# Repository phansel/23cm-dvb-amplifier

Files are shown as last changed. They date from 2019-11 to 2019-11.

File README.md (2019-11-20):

# 23cm DVB amplifier

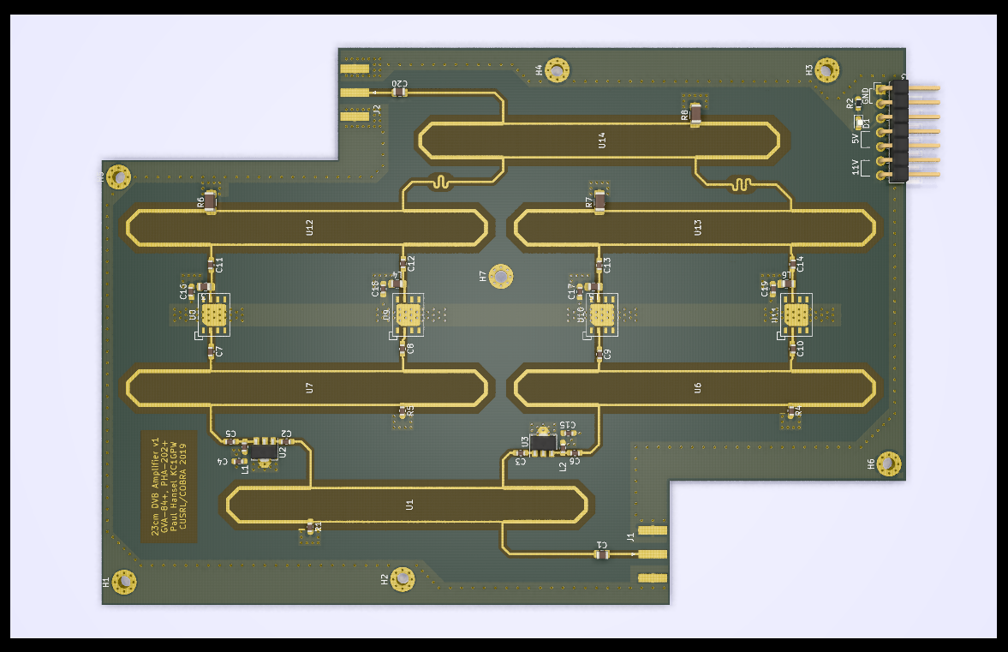
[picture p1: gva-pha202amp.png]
23cm DVB amplifier Amplifier image


This amplifier was designed in early 2019 for use as a telemetry/DVB radio for the University of Colorado COBRA/SRL rocket avionics project.

- ~ 4 watts (36 dBm) power output
- ~ 45 dB gain
- 1249 MHz center frequency

Note: editing this project requires at least KiCAD 5.99.

Copyright Paul Hansel (KC1GPW), 2019

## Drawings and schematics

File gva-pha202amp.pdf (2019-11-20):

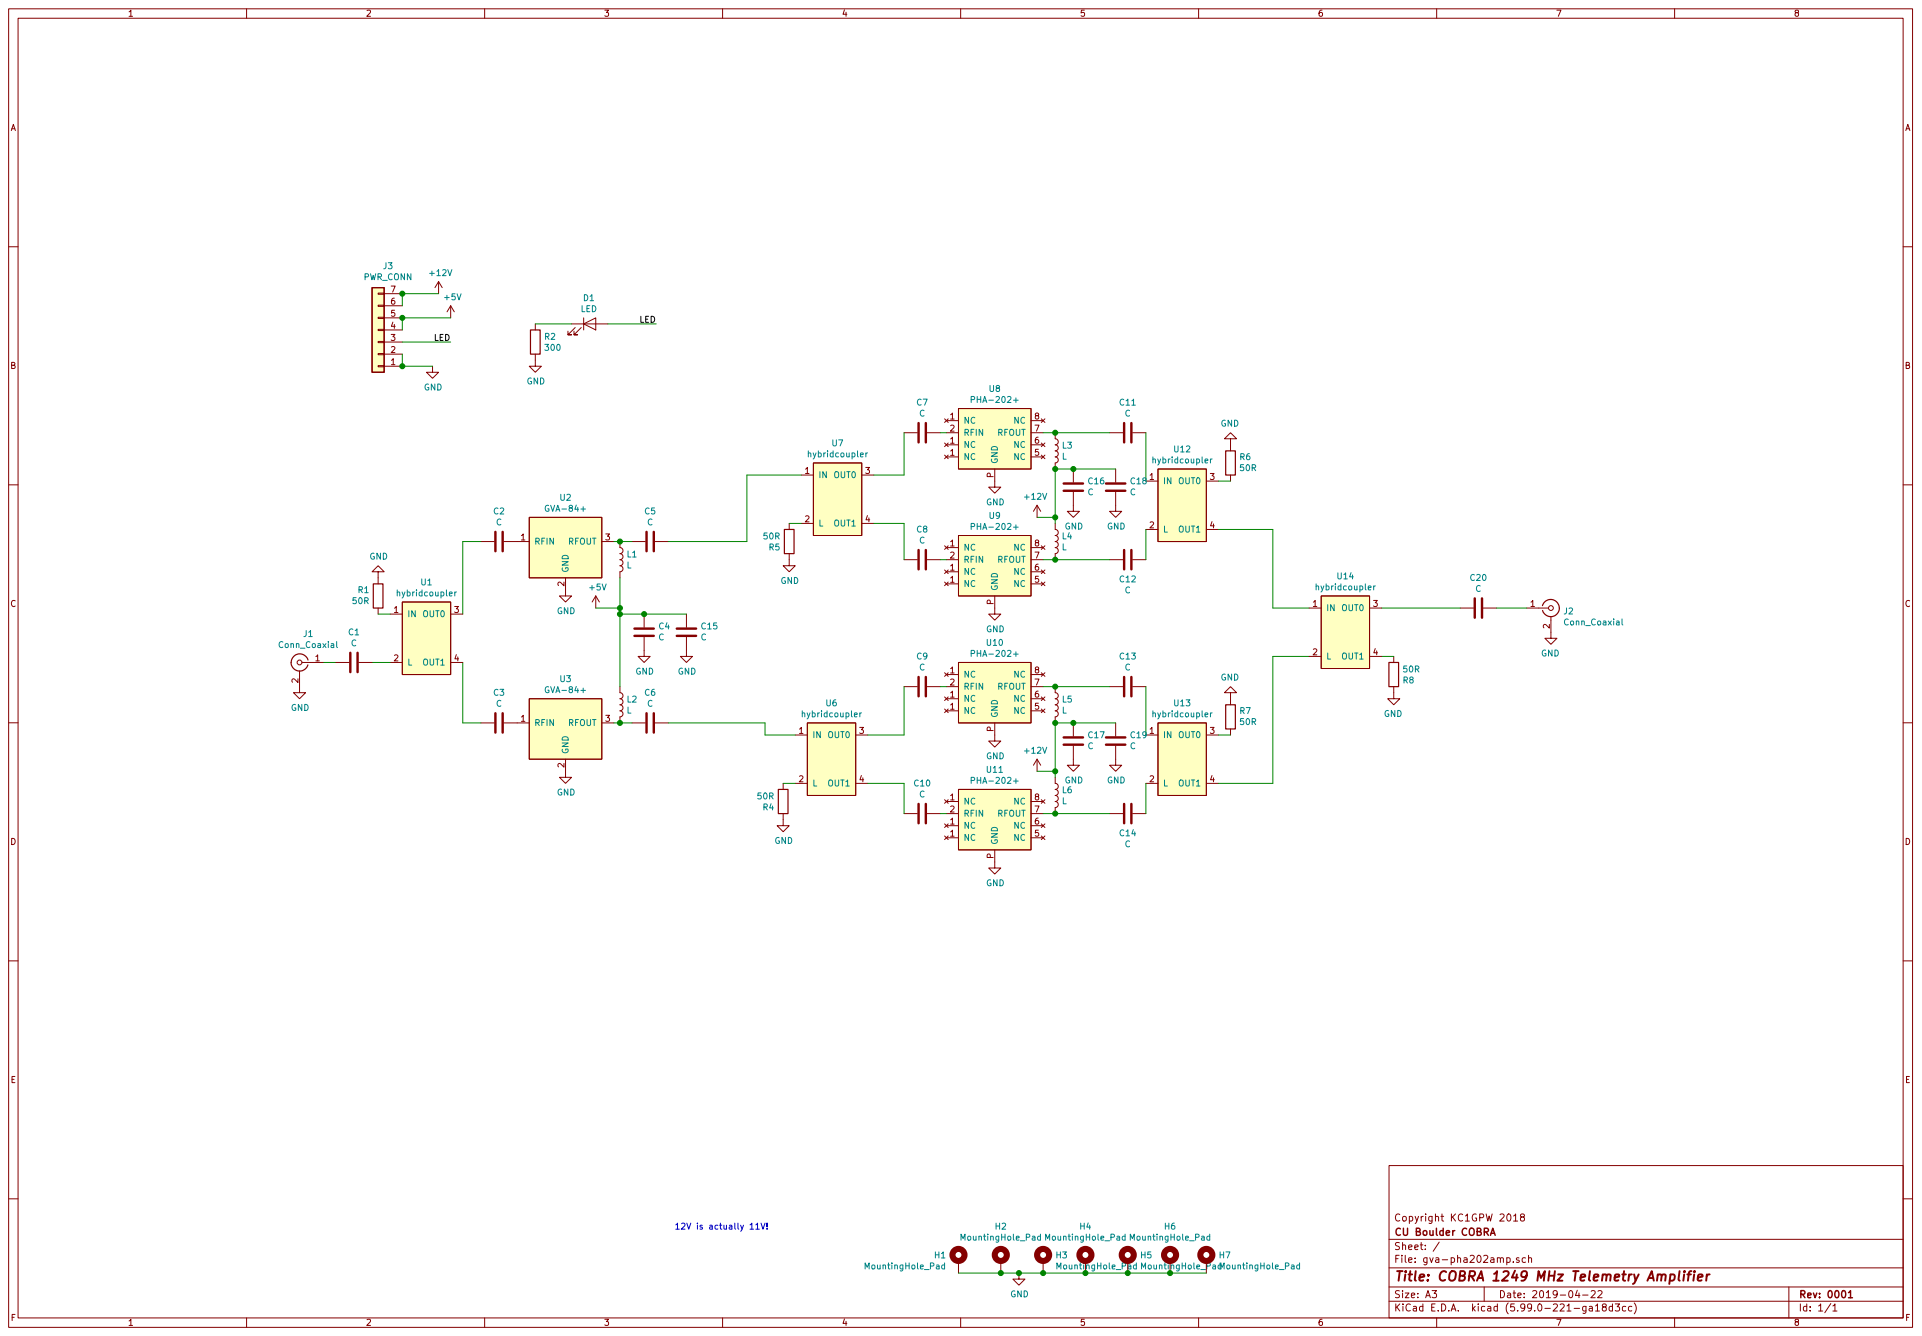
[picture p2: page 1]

P U8 PHA-202+ NC 1 NC 1 NC 1 RFIN 2 NC 5 NC 6 RFOUT 7 NC 8 GND

2 RFOUT 3 U3 GVA-84+ NC 1 NC 1 NC 1 RFIN 2 NC 5 NC 6 RFOUT 7 NC 8 GND

2 RFOUT 3 U2 GVA-84+ RFIN 1 GND

P U11 PHA-202+ GND GND GND GND

P U9 PHA-202+ NC 1 NC 1 NC 1 RFIN 2 NC 5 NC 6 RFOUT 7 NC 8 GND

P U10 PHA-202+ NC 1 NC 1 NC 1 RFIN 2 NC 5 NC 6 RFOUT 7 NC 8 GND

Copyright KC1GPW 2018
File: gva-pha202amp.sch Sheet: / CU Boulder COBRA

Id: 1/1 Title: COBRA 1249 MHz Telemetry Amplifier

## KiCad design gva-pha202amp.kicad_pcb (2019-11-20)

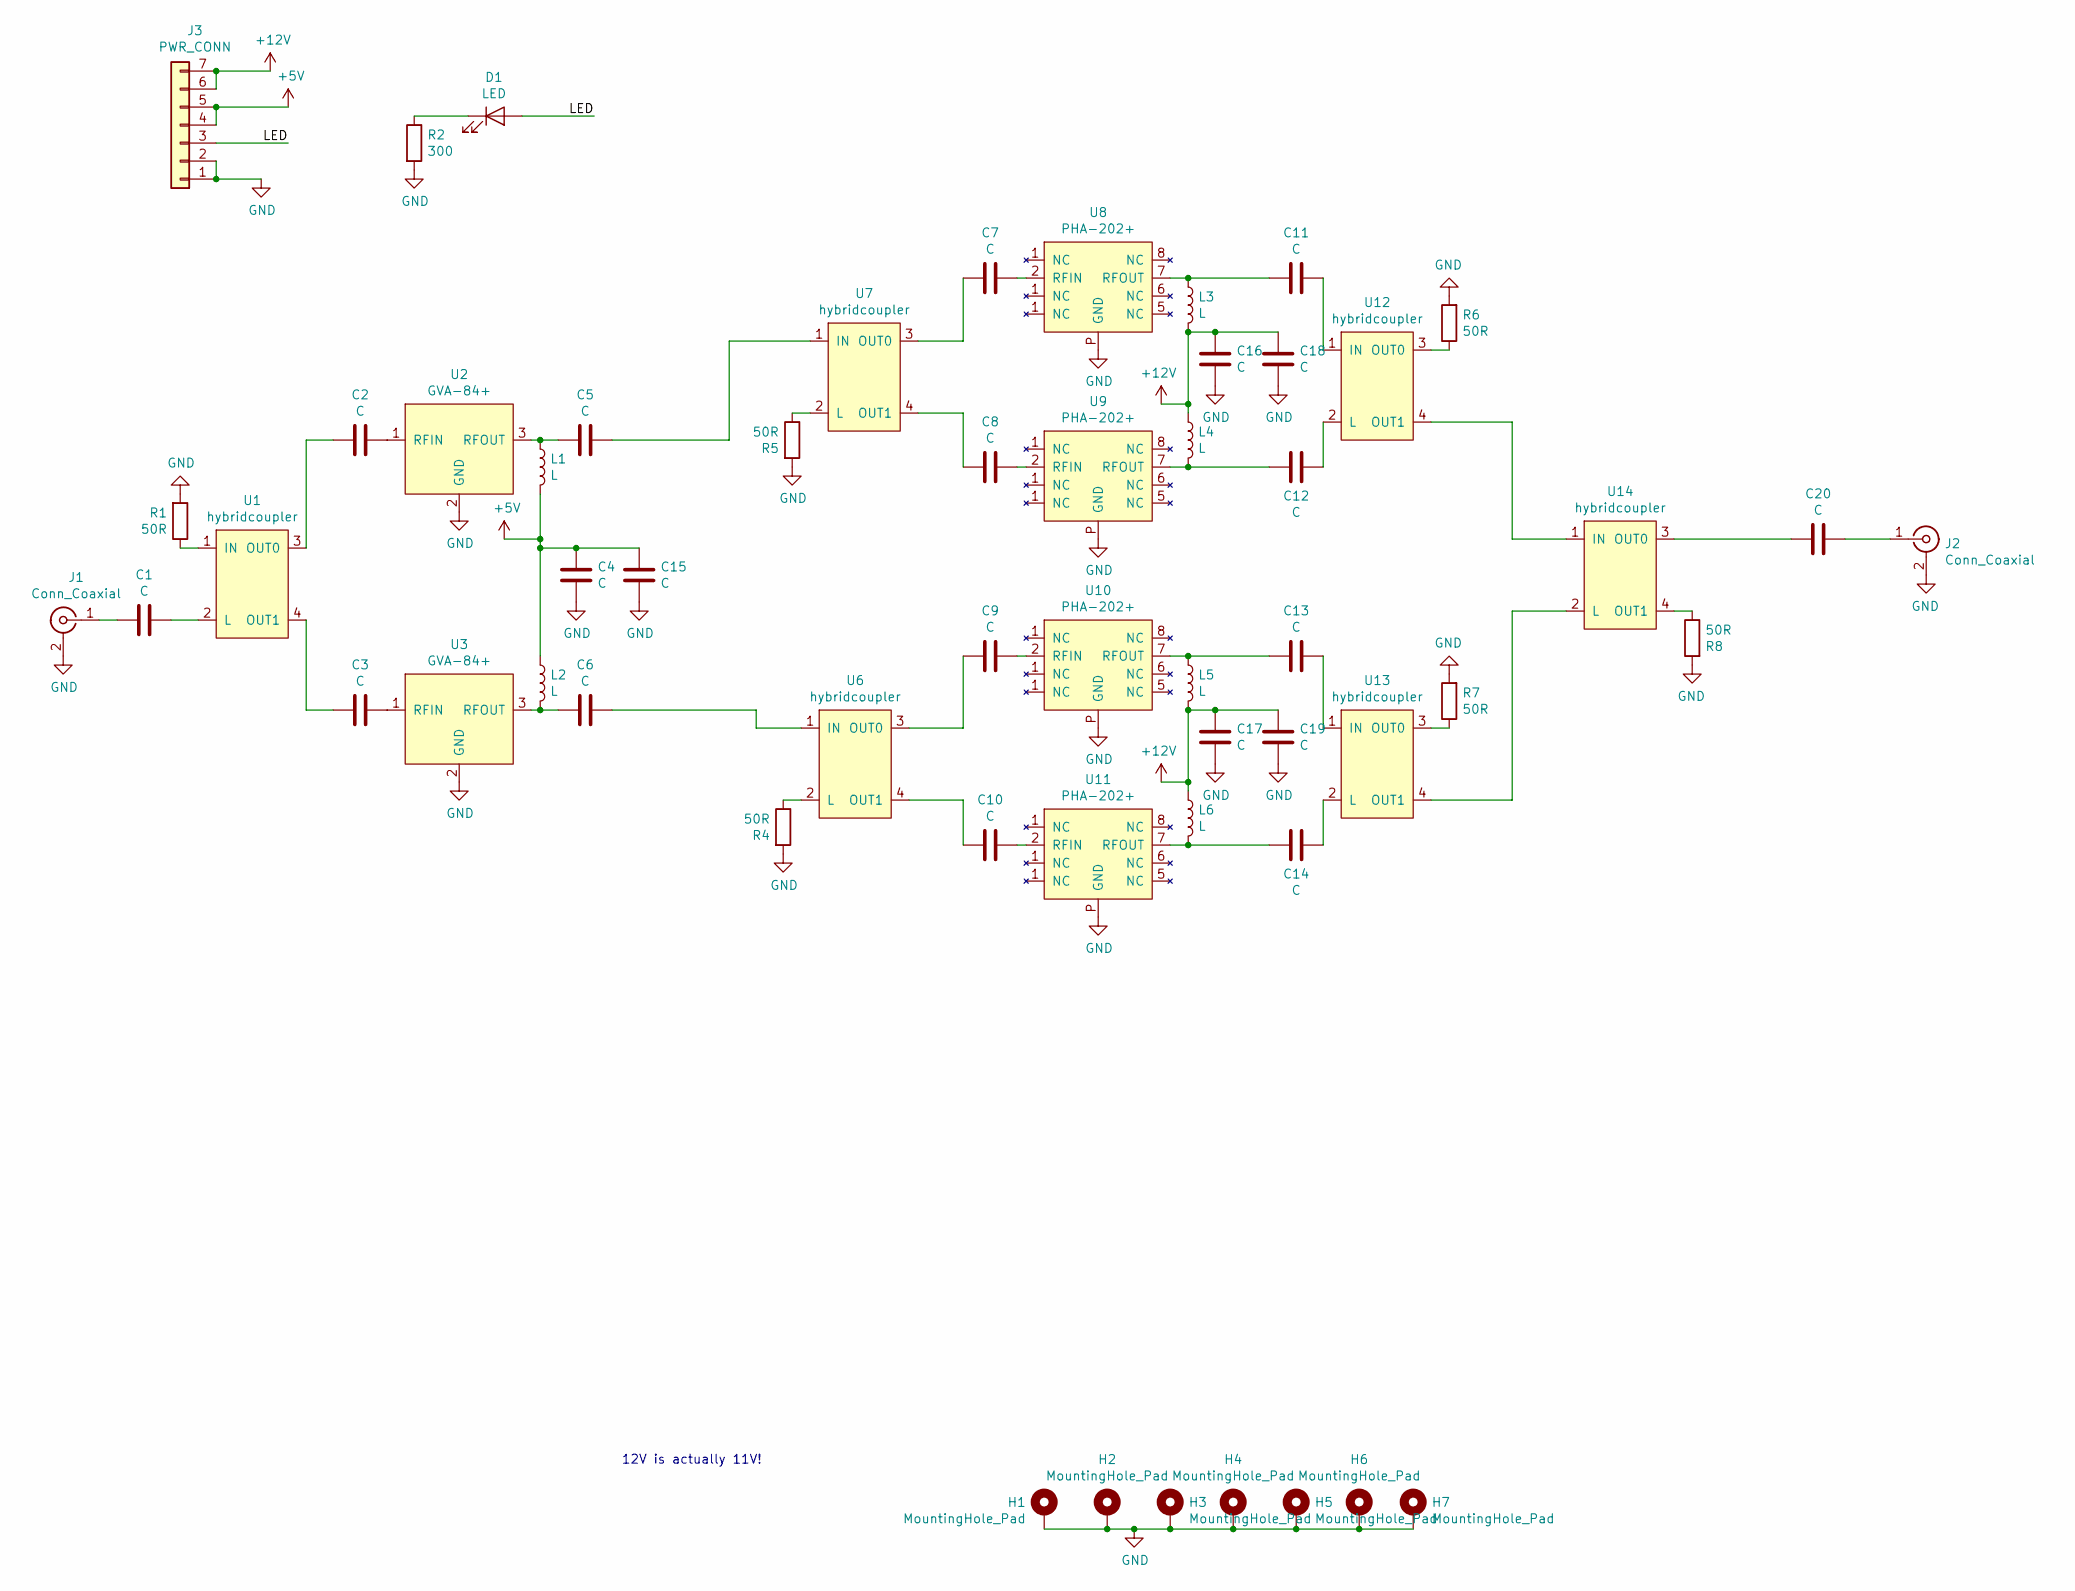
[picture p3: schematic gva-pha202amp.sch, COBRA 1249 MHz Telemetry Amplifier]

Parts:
C1, C20: C; C_0805_2012Metric
C2, C3, C4, C5, C6, C7, C8, C9, C10, C11, C12, C13, C14, C15, C16, C17, C18, C19: C; C_0603_1608Metric_Pad1.05x0.95mm_HandSolder
D1: LED; LED_0603_1608Metric
H1, H2, H3, H4, H5, H6, H7: MountingHole_Pad; MountingHole_2.2mm_M2_Pad_Via
J1, J2: Conn_Coaxial; SMA_Amphenol_132289_EdgeMount
J3: PWR_CONN; PinHeader_1x07_P2.54mm_Horizontal
L1, L2: L; C_0603_1608Metric_Pad1.05x0.95mm_HandSolder
L3, L4, L5, L6: L; C_0805_2012Metric_Pad1.15x1.40mm_HandSolder
R1, R4, R5: 50R; C_0603_1608Metric_Pad1.05x0.95mm_HandSolder
R2: 300; R_0603_1608Metric
R6, R7, R8: 50R; C_1206_3216Metric_Pad1.42x1.75mm_HandSolder
U1, U6, U7, U12, U13, U14: hybridcoupler; hybrid-branchline-coupler-1249
U2, U3: GVA-84+; SOT-89-3
U8, U9, U10, U11: PHA-202+; DL1636

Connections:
+5V: C4.2, C15.2, J3.4, J3.5, L1.2, L2.1
+12V: C16.2, C17.2, C18.2, C19.2, J3.6, J3.7, L3.2, L4.1, L5.2, L6.1
/LED: D1.2 (A), J3.3
GND: C4.1, C15.1, C16.1, C17.1, C18.1, C19.1, H1.1, H2.1, H3.1, H4.1, H5.1, H6.1, H7.1, J1.2 (Ext), J2.2 (Ext), J3.1, J3.2, R1.2, R2.2, R4.2, R5.2, R6.2, R7.2, R8.2, U2.2 (GND), U3.2 (GND), U8.P (GND), U9.P (GND), U10.P (GND), U11.P (GND)
unnamed: C1.1, U1.2 (L)
unnamed: C1.2, J1.1 (In)
unnamed: C2.1, U2.1 (RFIN)
unnamed: C2.2, U1.3 (OUT0)
unnamed: C3.1, U3.1 (RFIN)
unnamed: C3.2, U1.4 (OUT1)
unnamed: C5.1, U7.1 (IN)
unnamed: C5.2, L1.1, U2.3 (RFOUT)
unnamed: C6.1, U6.1 (IN)
unnamed: C6.2, L2.2, U3.3 (RFOUT)
unnamed: C7.1, U8.2 (RFIN)
unnamed: C7.2, U7.3 (OUT0)
unnamed: C8.1, U9.2 (RFIN)
unnamed: C8.2, U7.4 (OUT1)
unnamed: C9.1, U10.2 (RFIN)
unnamed: C9.2, U6.3 (OUT0)
unnamed: C10.1, U11.2 (RFIN)
unnamed: C10.2, U6.4 (OUT1)
unnamed: C11.1, U12.1 (IN)
unnamed: C11.2, L3.1, U8.7 (RFOUT)
unnamed: C12.1, U12.2 (L)
unnamed: C12.2, L4.2, U9.7 (RFOUT)
unnamed: C13.1, U13.1 (IN)
unnamed: C13.2, L5.1, U10.7 (RFOUT)
unnamed: C14.1, U13.2 (L)
unnamed: C14.2, L6.2, U11.7 (RFOUT)
unnamed: C20.1, J2.1 (In)
unnamed: C20.2, U14.3 (OUT0)
unnamed: D1.1 (K), R2.1
unnamed: R1.1, U1.1 (IN)
unnamed: R4.1, U6.2 (L)
unnamed: R5.1, U7.2 (L)
unnamed: R6.1, U12.3 (OUT0)
unnamed: R7.1, U13.3 (OUT0)
unnamed: R8.1, U14.4 (OUT1)
unnamed: U12.4 (OUT1), U14.1 (IN)
unnamed: U13.4 (OUT1), U14.2 (L)

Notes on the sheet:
12V is actually 11V!

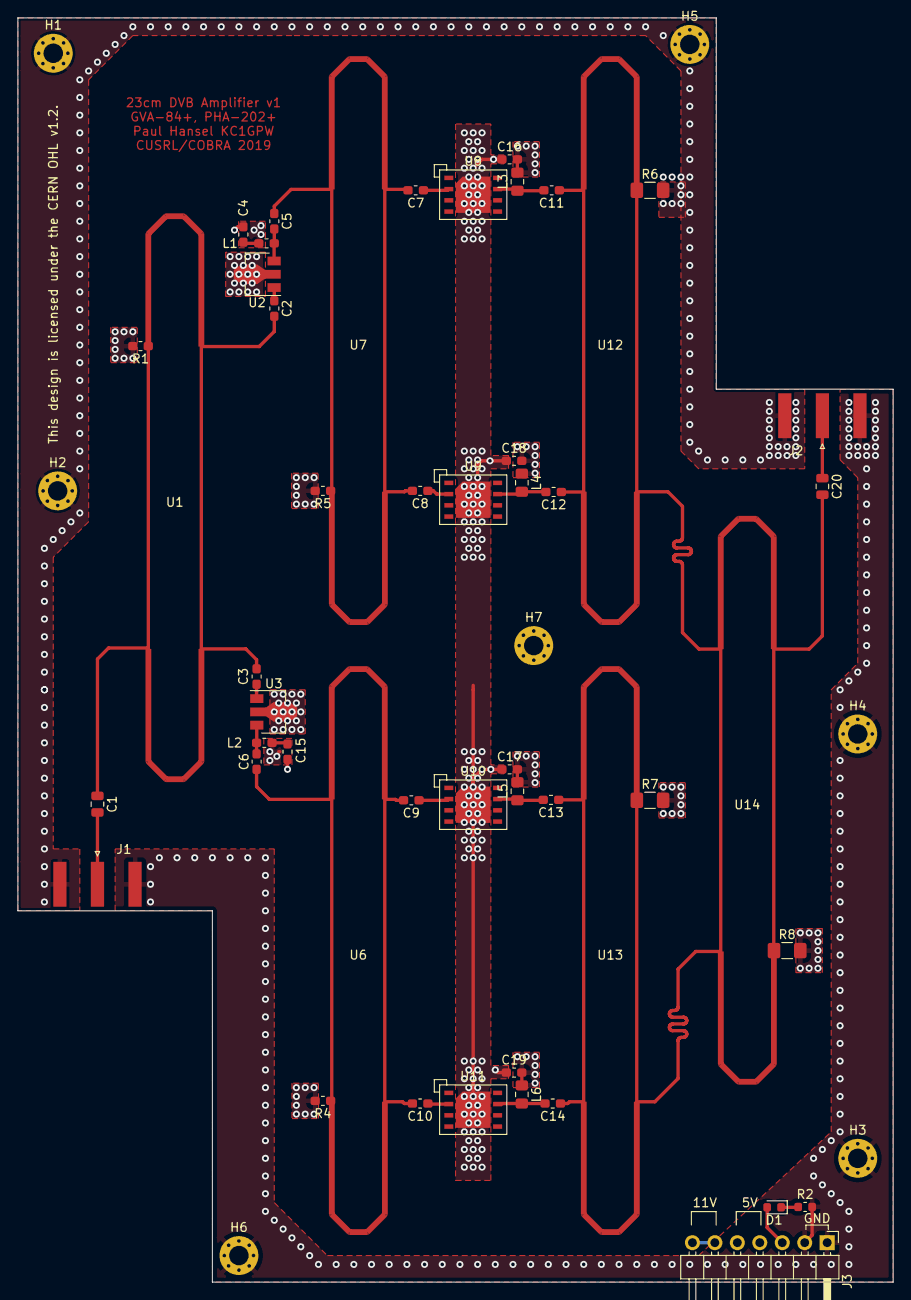
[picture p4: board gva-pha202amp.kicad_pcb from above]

Board: 4 copper layers, 99.0 x 143.0 mm, 56 parts (0 on the bottom side), 41 nets.

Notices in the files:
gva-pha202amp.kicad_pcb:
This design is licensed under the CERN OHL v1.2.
